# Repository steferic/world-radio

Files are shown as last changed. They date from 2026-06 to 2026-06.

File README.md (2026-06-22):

# World Radio — e-ink globe

A hardware "world radio": a black-and-white e-ink globe you spin between internet
radio stations, in the spirit of [Radio Garden](https://radio.garden). This repo
starts with the **visualization** — a browser prototype of the globe + station
markers + snap navigation — written so the render code ports almost line-for-line
to an **ESP32-S3** driving a B&W e-ink panel.

> A terminal spin-off grew out of this prototype — a braille-rendered globe you can
> run in your shell — and now lives in its own repo, **terminal-radio**.

## Why a browser prototype first

The globe is just math writing into a 1-bit framebuffer. That framebuffer is
identical whether it lives in a `<canvas>` or in the ESP32's RAM. So we prove the
*look and feel* at web-iteration speed, then port the ~200 lines of pure render
code to C. See [`firmware-notes/ESP32-PORTING.md`](firmware-notes/ESP32-PORTING.md).

## Run it

```bash
cd world-radio
npm run dev          # or: node server.mjs
# open http://localhost:4173
```

No build step, no dependencies. The coastline data is vendored (`public/coastline.geojson`,
Natural Earth 110m).

## Controls

| Action | Input |
|---|---|
| Next / previous station | `→` / `←` (or `[` `]`, or the Prev/Next buttons) |
| Select a station | click its marker on the globe, or a row in the sidebar |
| Play / stop stream | `Space` or the ▶/■ button |
| Full refresh (clear ghosting) | `F` or the **Full refresh** button |
| Change panel size | the **Panel** dropdown (4.2″, 1.54″ square, 2.9″, 7.5″) |
| Render style | the **Render style** dropdown (see below) |
| Graticule | checkbox |
| **Simulate e-ink refresh** | checkbox — snap navigation + partial/full refresh + **ghosting** |
| Load real geolocated stations | **Load live stations** (pulls from radio-browser.info) |

## Render styles (and why they matter for e-ink)

A B&W e-ink panel can only do black and white, and **dense dithered regions ghost
badly under partial refresh.** The render styles let you weigh look vs. e-ink
behavior — turn on *Simulate e-ink refresh* and navigate a few times to feel it:

| Style | Look | E-ink behavior |
|---|---|---|
| **Filled land** (default) | Solid black continents, white ocean | Best — ocean stays clean, minimal ghosting |
| **Gray land** | 50% dithered continents | Good — dither only over land, ocean clean |
| **Wireframe** | Coastline outlines only | Cleanest — fewest black pixels |
| **Shaded sphere** | Lit 3D sphere via full-disc dither | Prettiest, but **ghosts heavily** — full-refresh only |

The land fill uses an **inverse-orthographic projection + point-in-polygon** test
per disc pixel (`fillLand` / `unproject` in `projection.js`) — it ports to the chip
unchanged and clips at the limb for free.

## The e-ink simulation (what to look for)

With *Simulate e-ink refresh* on, the prototype models how the real panel behaves so
you can make design calls **before buying hardware**:

- **Partial refresh** (most moves): fast (~0.3s), no flash — but leaves a faint ghost
  where pixels went black→white. Ghosts accumulate.
- **Full refresh** (every 6th move, or press `F`): the black/white flash (~2s) that
  clears all ghosting.

Try **Shaded** vs **Filled** in e-ink mode and watch the difference — this is the #1
thing to validate on real glass, and it strongly favors the filled/wire styles.

## Design decisions

- **1-bit, pixel-faithful.** Everything renders at the panel's *native* resolution
  (e.g. 400×300), is hard-thresholded to pure black/white (even the text), then
  upscaled nearest-neighbor so what you see on screen is what the e-ink shows.
- **Discrete snap navigation.** E-ink can't do smooth rotation; instead you snap
  station-to-station, one partial refresh per move — a vintage shortwave-dial feel
  that *matches* the hardware's strengths and frees the CPU for audio during playback.
- **Sphere shading via ordered dither.** A 4×4 Bayer matrix fakes a lit sphere on a
  panel that only has two colors.

## Project layout

```
world-radio/
├── index.html              # device shell + controls
├── styles.css
├── server.mjs              # tiny dependency-free static server
├── public/
│   ├── coastline.geojson   # vendored Natural Earth 110m coastlines (source)
│   ├── coastline.js        # inlined coastlines (window.COASTLINE)
│   ├── land.geojson        # vendored Natural Earth 110m land polygons (source)
│   └── land.js             # inlined landmasses + bboxes (window.LAND)
├── src/
│   ├── projection.js       # PORTABLE renderer — DOM-free, maps to ESP32 C
│   ├── stations.js         # curated global station table
│   └── app.js              # browser glue: canvas, animation, audio, input, e-ink sim
└── firmware-notes/
    └── ESP32-PORTING.md    # bill of materials + the port plan
```

The one file that matters for hardware is [`src/projection.js`](src/projection.js):
keep it DOM-free and dependency-free. Everything browser-specific lives in `app.js`
and gets replaced on the chip by the e-ink driver, a rotary encoder, and I2S audio.

## Data sources

- **Geography:** [Natural Earth](https://www.naturalearthdata.com/) 110m coastlines.
- **Stations + streams:** [radio-browser.info](https://www.radio-browser.info) — free,
  open, ~50k stations, many with lat/long and direct stream URLs.

## Roadmap

1. ✅ Browser prototype of the globe (this).
2. Bring up e-ink: render one static globe frame from the ported `projection.c`.
3. Rotary-encoder navigation + partial refresh between stations.
4. WiFi + internet-radio streaming (ESP32-audioI2S → I2S DAC → speaker).
5. radio-browser fetch + on-device station cache.
6. Enclosure + battery.

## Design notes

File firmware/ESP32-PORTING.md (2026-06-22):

# Porting the globe to ESP32-S3

The browser prototype was written so the rendering is a straight port. This doc is
the bridge from `src/projection.js` to firmware: the bill of materials, the library
choices, and exactly how each piece moves onto the chip.

## Bill of materials

| Part | Recommendation | Notes |
|---|---|---|
| **MCU** | ESP32-S3 with **PSRAM** — e.g. `ESP32-S3-DevKitC-1 N16R8` (16 MB flash / 8 MB PSRAM), or Seeed XIAO ESP32-S3 | PSRAM is non-negotiable: audio decode buffers + framebuffer + WiFi stack. The S3's FPU makes the projection math cheap. |
| **Display** | Waveshare **4.2″ B&W e-ink**, 400×300, SPI (SSD1683/UC8176) | Square 1.54″ 200×200 is the most globe-like if you want compact. Both do partial refresh. |
| **Audio DAC/amp** | **MAX98357A** (I2S, mono, built-in 3W amp) → small speaker | Or PCM5102 for line-out. Dead-simple wiring, 3 signal pins. |
| **Input** | Rotary encoder with push (e.g. EC11) | Rotate = tune between stations; push = play/stop. Optional 1–2 buttons. |
| **Power** | LiPo + TP4056 charger (if portable) | E-ink holds its image at **zero power**, so idle/standby battery life is excellent. |

Everything else (WiFi antenna) is on the S3 module.

## Software stack

- **Framework:** Arduino-ESP32 (fastest path — the libraries below are first-class
  there). ESP-IDF works too if you prefer.
- **E-ink driver:** [`GxEPD2`](https://github.com/ZinggJM/GxEPD2) — supports the
  Waveshare panels and, crucially, **partial refresh**.
- **Audio streaming:** [`ESP32-audioI2S`](https://github.com/schreibfaul1/ESP32-audioI2S)
  — `Audio.connecttohost("http://stream...")` handles Icecast/Shoutcast MP3/AAC and
  pushes straight to I2S. Internet-radio-on-ESP32 is a solved, well-documented problem.
- **JSON (for live stations):** `ArduinoJson` to parse radio-browser.info responses.

## How each prototype piece maps to the chip

### Framebuffer (`projection.js` → `projection.c`)
- JS uses one byte per pixel (`Uint8Array`). On the chip, use GxEPD2's native
  **packed 1bpp buffer** (`width*height/8` bytes; 400×300 = **15 KB**).
- `setPixel(x,y,color)` becomes a bit set/clear in that packed buffer (or just call
  `display.drawPixel(x,y, color ? GxEPD_BLACK : GxEPD_WHITE)`).
- `drawLine`, `fillCircle`, `strokeCircle`, the Bayer dither, and **`project()` /
  `makeCenter()` / `renderGlobe()` port verbatim** — they're already pure number
  crunching. Use `float` (the S3 has hardware FP) or fixed-point if you want to shave
  cycles; it's not the bottleneck.

### Coastline + land data
- Convert `public/coastline.geojson` → a C header of scaled integers once, at build
  time. ~5,128 points × (lon,lat) as `int16_t` (degrees × 100) ≈ **20 KB** in flash —
  trivial. A 15-line Node script emits `coastline.h` as `const int16_t[]` with
  per-polyline length prefixes. (`public/coastline.js` already does this transform to
  JS; the C header is the same data.)
- For the **filled** styles, also bake `public/land.js` → `land.h` (landmasses +
  per-landmass bbox, another ~20 KB). `fillLand` / `unproject` / `pointInFeature` in
  `projection.js` port unchanged — the bbox reject keeps the per-pixel point-in-polygon
  cheap. **Prefer the filled or wireframe styles on real hardware**: the prototype's
  e-ink simulation shows the shaded (full-disc dither) style ghosts badly under partial
  refresh, while solid fills keep the ocean clean and refresh cleanly.

### Display loop (the snap model pays off here)
- Render the globe into the 1bpp buffer, then `display.display(true)` for a **partial
  refresh** (~0.3–0.5 s on the 4.2″). Do a **full refresh** (~2 s) every N moves to
  clear ghosting.
- Because navigation is discrete snaps, the panel only refreshes *when you turn the
  encoder* — the rest of the time the CPU is free for audio.

### Audio
- WiFi connect → `audio.connecttohost(station.url)` → I2S → MAX98357A → speaker.
- Runs continuously while the e-ink sits static. This synergy (slow display + steady
  audio) is exactly why ESP32-S3 + e-ink is a good fit.

### Stations
- Ship the curated table (`stations.js`) as a C struct array in flash.
- Optionally fetch radio-browser.info over HTTPS at boot, parse with ArduinoJson,
  cache to **NVS** so you're not hitting the network every power-on.

### Input
- Rotary encoder ISR increments/decrements `selectedStation`; ease `currentCenter`
  toward the target lon/lat over a few partial refreshes (or snap in one). Encoder
  push toggles `audio.pauseResume()`.

## Memory budget (sanity check)

| Item | Size |
|---|---|
| 1bpp framebuffer (400×300) | 15 KB |
| Coastline table | ~20 KB |
| Station table | < 5 KB |
| Audio decode + ring buffers | hundreds of KB → **PSRAM** |

Comfortable on an S3 with 8 MB PSRAM. This is why the BOM insists on the `R8` part.

## Suggested bring-up order

1. `GxEPD2` "hello world" on the panel — confirm wiring + refresh.
2. Drop in ported `projection.c` + `coastline.h`; render **one static globe frame**.
   This single step proves the entire visual port.
3. Add the rotary encoder + partial-refresh navigation between stations.
4. Add WiFi + `ESP32-audioI2S` streaming of the selected station.
5. Add radio-browser fetch + NVS caching.
6. Enclosure + battery.

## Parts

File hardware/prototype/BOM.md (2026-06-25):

# Prototype Bill of Materials (BOM)

- Processor
	- ESP32 Dev Kit
- Display
	- GMT024-10
		- Powered by ST7789 driver IC.

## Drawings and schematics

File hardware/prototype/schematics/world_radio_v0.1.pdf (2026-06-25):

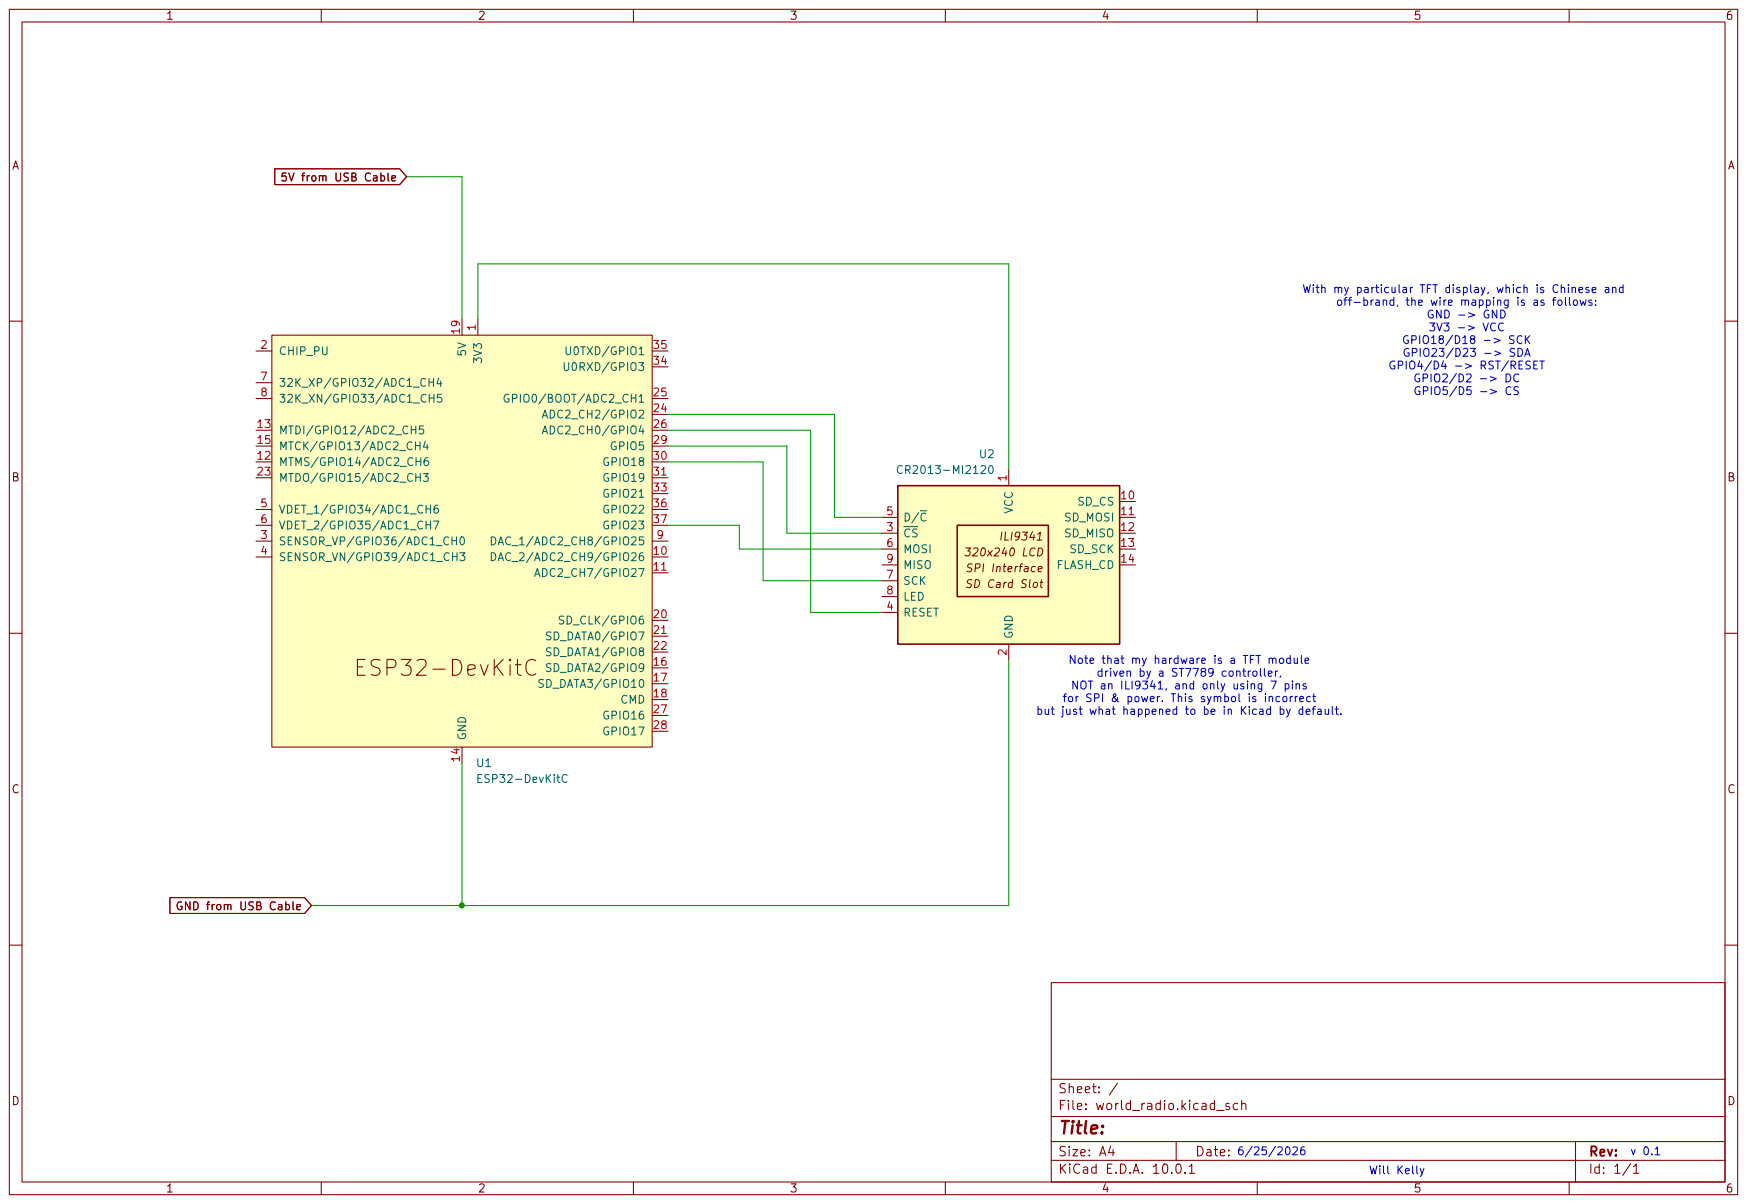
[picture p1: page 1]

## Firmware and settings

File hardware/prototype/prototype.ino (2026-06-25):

/*
  Wireframe Globe — ST7789 TFT
  -----------------------------------------------------------
  Spinning wireframe globe on a 240×320 ST7789 panel.
*/

#include <Arduino.h>
#include <SPI.h>
#include "config.h"
#include "geometry.h"
#include "display.h"
#include "network.h"

float currentSpin = 0;

void setup() {
  Serial.begin(115200);
  delay(200);
  wifiInit();
  displayInit();
}

void loop() {
  wifiUpdate();
  for (int half = 0; half < 2; half++) {
    int yOffset = half * HALF_HEIGHT;
    halfCanvas->fillScreen(ST77XX_BLACK);
    drawSphereFrame(*halfCanvas, currentSpin, yOffset);
    tft.drawRGBBitmap(0, yOffset, halfCanvas->getBuffer(), PANEL_WIDTH, HALF_HEIGHT);
  }

  currentSpin += ROTATION_STEP_DEG;
  if (currentSpin >= 360.0f) currentSpin -= 360.0f;

  delay(FRAME_DELAY_MS);
}

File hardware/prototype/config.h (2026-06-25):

#ifndef CONFIG_H
#define CONFIG_H

// TFT pins
#define TFT_CS   5
#define TFT_DC   2
#define TFT_RST  4

// Display setup
#define PANEL_WIDTH  240
#define PANEL_HEIGHT 320
#define HALF_HEIGHT  (PANEL_HEIGHT / 2)

// Sphere appearance
#define SPHERE_RADIUS_PX   95
#define CENTER_X           120
#define CENTER_Y           160
#define NUM_LAT_RINGS      7
#define NUM_LON_LINES      8
#define SEGMENTS_PER_LINE  28
#define TILT_DEG           20.0
#define ROTATION_STEP_DEG  4.0
#define FRAME_DELAY_MS     5

#define RGB565(r, g, b) ((uint16_t)(((r & 0xF8) << 8) | ((g & 0xFC) << 3) | (b >> 3)))
#define COLOR_FRONT  ST77XX_CYAN
#define COLOR_BACK   RGB565(50, 50, 50)
#define COLOR_LIGHT_MODE false

// Wifi
#define WIFI_SSID "WIFISSID"
#define WIFI_PASS "WIFIPASSWORD"

#endif

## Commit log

2026-06-22 Initial commit: World Radio — e-ink globe
    A hardware "world radio": a black-and-white e-ink globe you spin between internet
    radio stations, in the spirit of Radio Garden. A browser prototype of the 1-bit
    orthographic globe + station markers + snap navigation, written so the render code
    ports to an ESP32-S3 driving a B&W e-ink panel (see firmware-notes/).
    The terminal spin-off now lives in its own repo (terminal-radio).
2026-06-25 Basic spinning globe on ESP32.
2026-06-25 Add schematic for prototype v0.1
    [world_radio.kicad_sch]
